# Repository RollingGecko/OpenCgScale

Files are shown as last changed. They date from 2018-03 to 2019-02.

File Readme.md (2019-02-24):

# Open CG-Scale

The complete project is open source. 

The weight and the CG is measured by 3 scale modules places under the landing gear of the airplane. Everything is powered by an ESP32.
The position of the CG is projected by a laser on the button of the plane. 

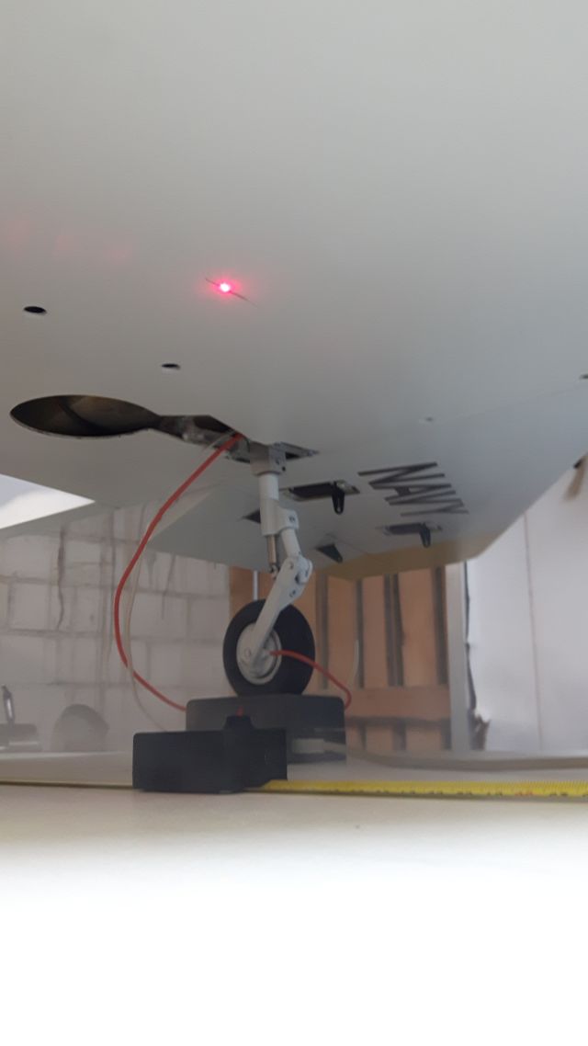
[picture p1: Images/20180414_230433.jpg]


Measuring of distance is supported by a laser, that points to the middle of the main gear.

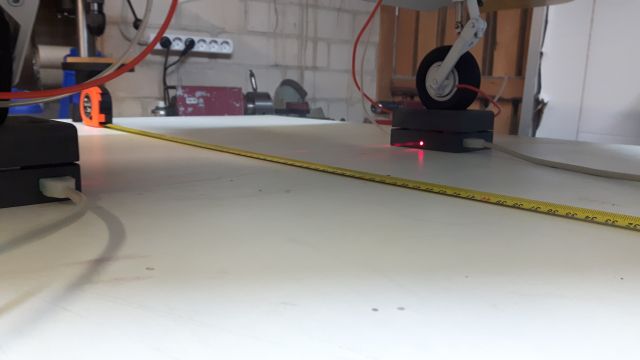
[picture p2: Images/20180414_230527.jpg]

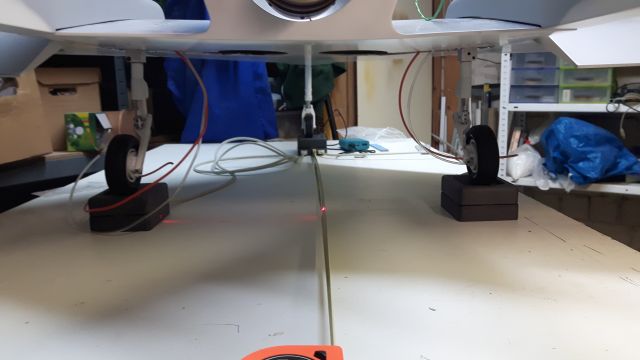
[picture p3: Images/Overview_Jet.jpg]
Overview Jet

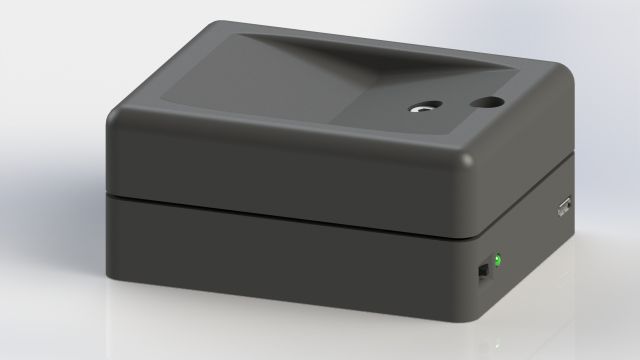
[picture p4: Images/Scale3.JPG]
Scale3


All information are shown on a Android app via bluetooth 4.0 low energy. The app was designed in [Thunkable](https://thunkable.com/#/). The design file is stored together
with the aplication AKP in the repo. [(Link)](https://github.com/RollingGecko/CgScale/tree/master/SRC/APP)

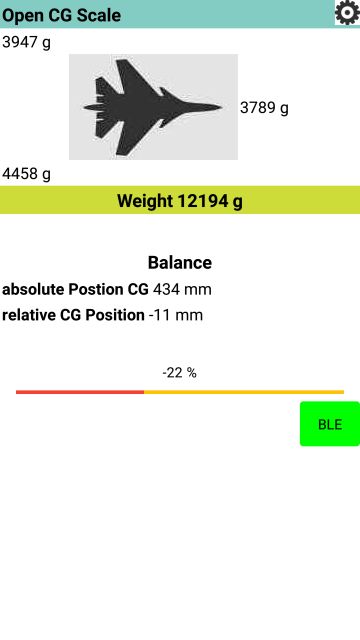
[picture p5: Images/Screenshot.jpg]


All parts are printed 3d. Files are provided as [(STL)](https://github.com/RollingGecko/CgScale/tree/master/Parts/STL). Some aluminium parts are required. But they can simply be cutted from aluminium profile [(PDF)](https://github.com/RollingGecko/CgScale/blob/master/Parts/Alu-Parts_Drawing.PDF).

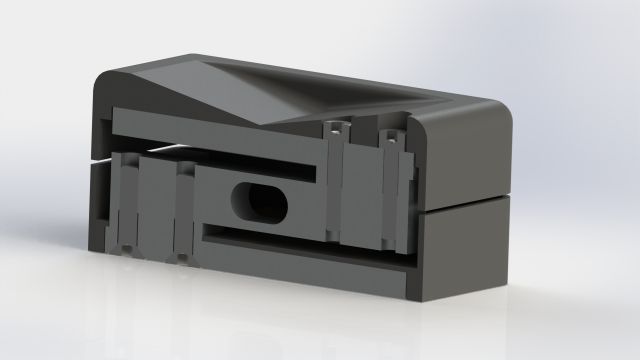
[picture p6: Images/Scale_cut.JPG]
Scale Cut


## Hardware
### Based on ESP32. 

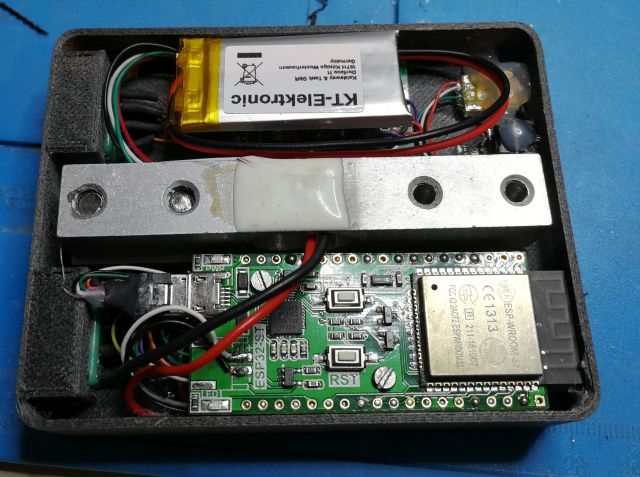
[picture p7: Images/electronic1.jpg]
Electronic1


* Used Board ESP32 WeMos LOLIN32 Lite V1.0.0
	* https://wiki.wemos.cc/products:lolin32:lolin32_lite
	* https://arduino-projekte.info/wemos-lolin32-lite/ (German)
* The Board provides an Lipo Battery Charger
### Scale

* Used 10 kg load cell together with the [HX-711](https://github.com/bogde/HX711.git) board you can find for example
  * on ebay: https://tinyurl.com/ybxn4rfh
  * on aliexpress: https://tinyurl.com/y78dd9gv

### Laser pointer module
 * From ebay like https://tinyurl.com/y8mcnznn
 * Aliexpress https://tinyurl.com/ydeltejj

## Used Libaries
* Used Libraries from espressif. See https://github.com/espressif/arduino-esp32/blob/master/docs/arduino-ide/boards_manager.md for installation.
* HX-711 Board: https://github.com/bogde/HX711.git

# Circuit

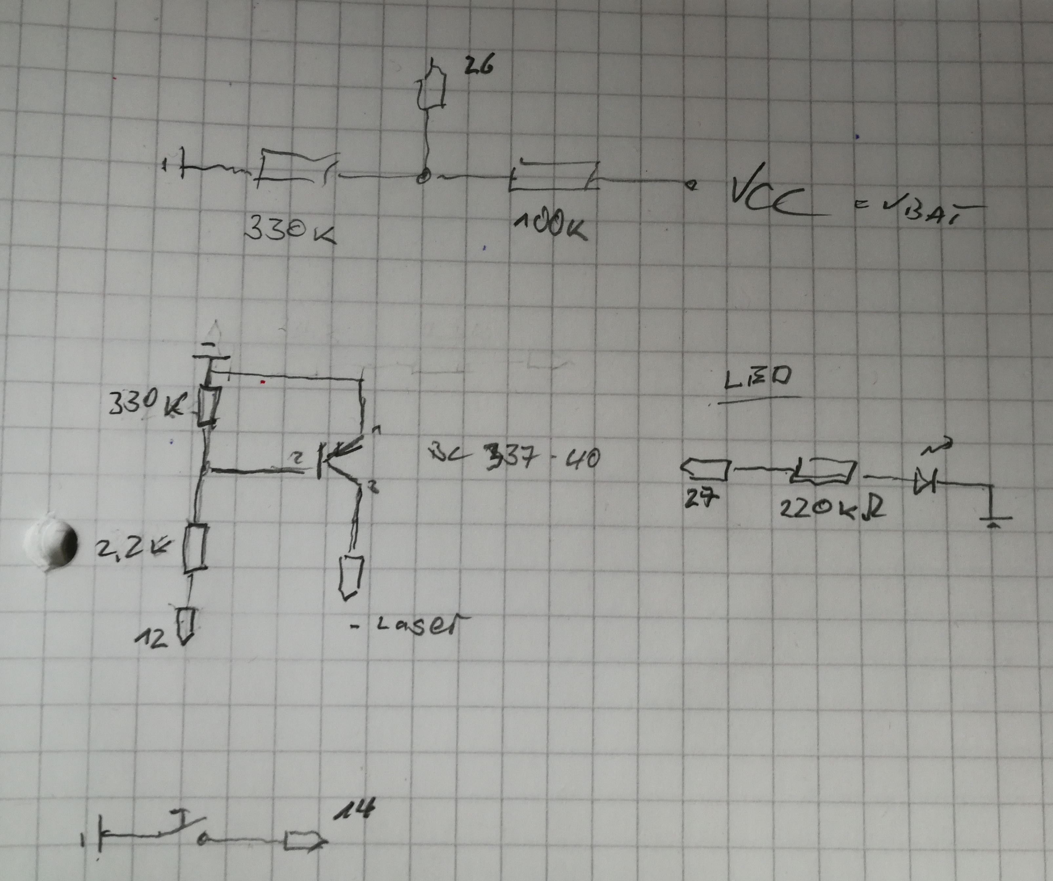
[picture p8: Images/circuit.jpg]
Circuit


The PIN-setting to the esp32 is configured in the config.h file.

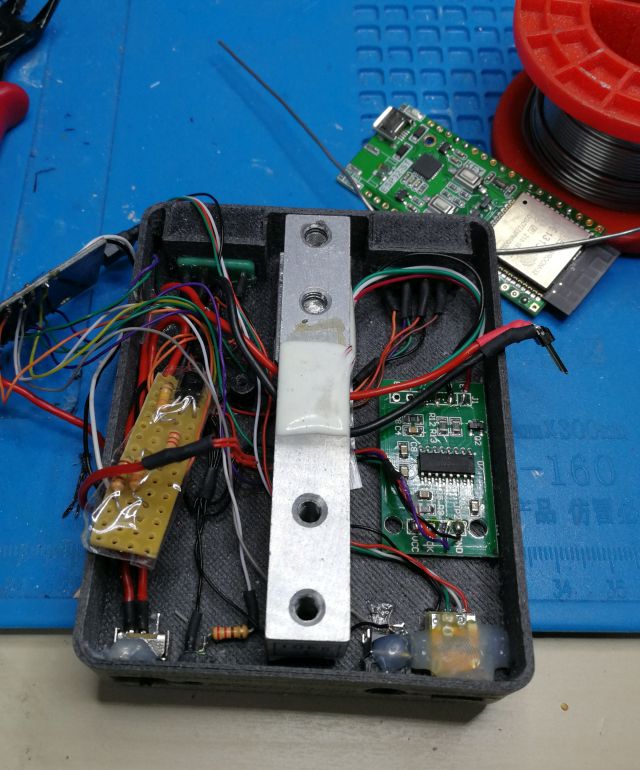
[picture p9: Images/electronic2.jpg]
Electronic2


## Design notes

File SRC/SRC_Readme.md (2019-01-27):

## Two programs available

### CG_Scale
The main finished program.

### ScaleBleDummy
A program to run a dummy on the ESP32 for APP - programming.

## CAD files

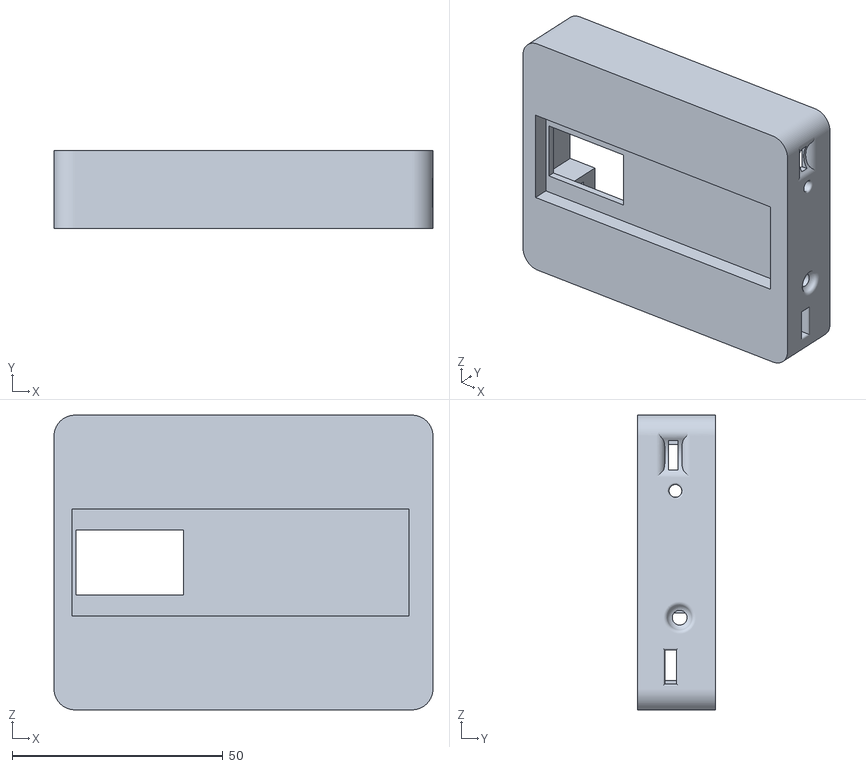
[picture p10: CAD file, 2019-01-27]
Parts/STL/CG_Scale_Main_Lower.STL
90.0 x 18.5 x 70.0

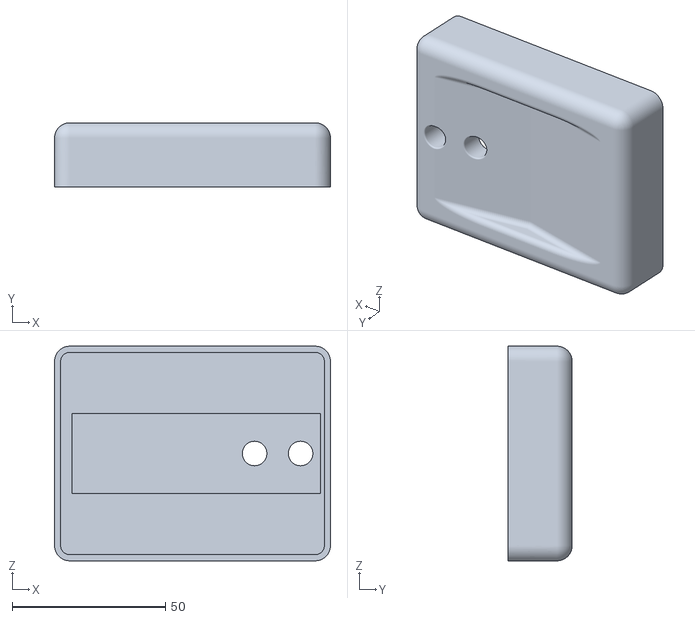
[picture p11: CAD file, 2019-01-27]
Parts/STL/CG_Scale_Main_Upper.STL
90.0 x 21.0 x 70.0

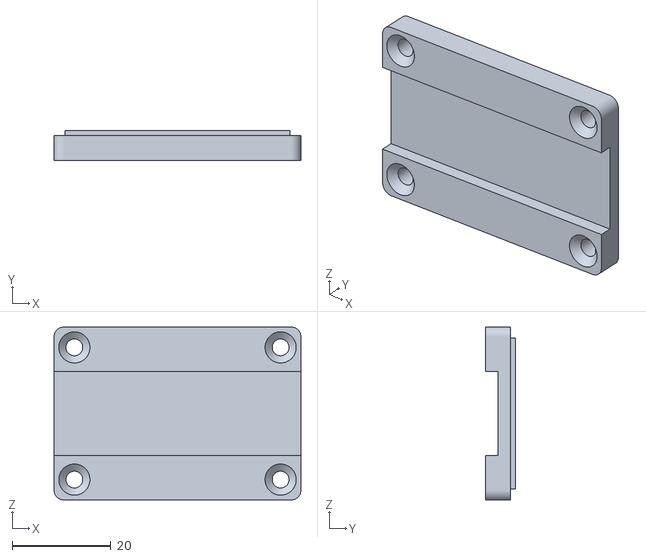
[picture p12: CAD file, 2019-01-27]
Parts/STL/CG_Laser_Pointer_Lower.STL
50.0 x 6.00 x 35.0

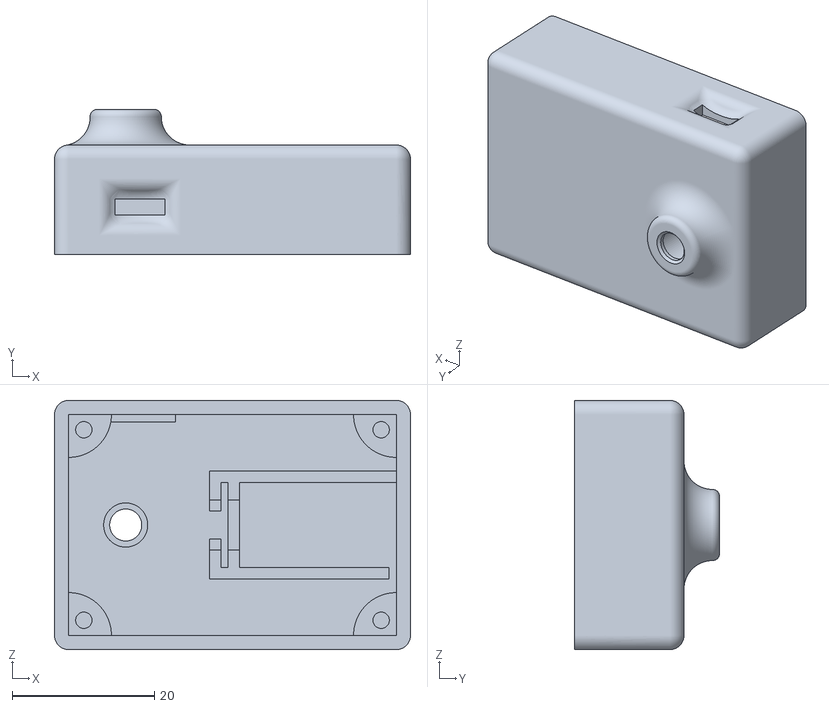
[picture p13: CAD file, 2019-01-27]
Parts/STL/CG_Laser_Pointer_Upper.STL
50.0 x 20.4 x 35.0

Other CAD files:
Parts/STL/CG_Scale_Lower_satelite.STL
Parts/STL/CG_Scale_Lower_Laser.STL

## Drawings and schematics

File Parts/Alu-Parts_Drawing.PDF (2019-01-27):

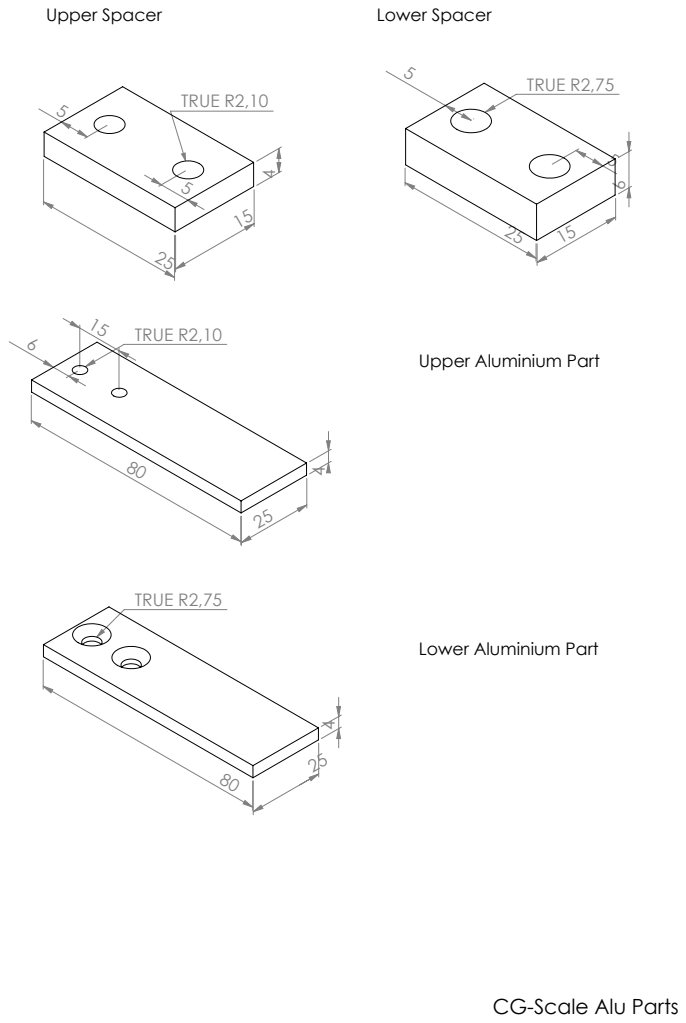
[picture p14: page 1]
TRUE R2,10 5; TRUE R2,10 15; TRUE R2,75; TRUE R2,75 5; Upper Spacer; Lower Spacer

Upper Aluminium Part

Lower Aluminium Part

CG-Scale Alu Parts

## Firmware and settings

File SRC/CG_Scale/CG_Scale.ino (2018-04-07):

#include "BLEDevice.h"
#include "BLEUtils.h"
#include "BLEServer.h"
#include "BLE2902.h"
#include "HX711.h"
#include "config.h"
#include "soc/rtc.h"

//Declaration of BLE Objects

bool deviceConnected = false;

BLECharacteristic *scaleValueMainCharacteristic;
BLECharacteristic *scaleValue1Characteristic;
BLECharacteristic *scaleValue2Characteristic;

//Declaratition of HX711 Scale Modules

HX711	scaleMain(SCALEDATAPIN_MAIN, SCALECLKPIN_MAIN, SCALEGAIN_MAIN);
HX711	scale1(SCALEDATAPIN_1, SCALECLKPIN_1, SCALEGAIN_1);
HX711	scale2(SCALEDATAPIN_2, SCALECLKPIN_2, SCALEGAIN_2);

int	ScaleReading_Main = 0.00;

//BLECharacteristic *configMeasureScale1Characteristic;
//BLECharacteristic *configMeasureScale2Characteristic;
//BLECharacteristic *configMeasureScale3Characteristic;

class MyServerCallbacks : public BLEServerCallbacks {
	void onConnect(BLEServer* pServer) {
		deviceConnected = true;
		Serial.println("Device connected.");
	};

	void onDisconnect(BLEServer* pServer) {
		deviceConnected = false;
		Serial.println("Device disconnected.");
	};
};


void setIntToCharacteristic(BLECharacteristic* charact, int value) {
	char txstr[8];
	itoa(value, txstr, 10);
	charact->setValue(txstr);
}

void scaleToBle(HX711* scale, BLECharacteristic* ble) {
	int scaleReading = 0;
	scale->read();
	scaleReading = round(scale->get_units(5));
	if (scaleReading <= 4)
	{
		scaleReading = 0;
	}

	Serial.print("Reading from ScaleModule: ");
	Serial.println(scaleReading);

	setIntToCharacteristic(ble, scaleReading);
	ble->notify();
}


volatile int buttonInterruptCount = 0;
unsigned long lastDebounceTime = 0;
unsigned long startButtonCountInterval = 0;
int numberOfInterrupts = 0;
portMUX_TYPE mux = portMUX_INITIALIZER_UNLOCKED;

boolean laserOn = false;

void IRAM_ATTR handleInterrupt() {
	portENTER_CRITICAL_ISR(&mux);
	buttonInterruptCount++;
	portEXIT_CRITICAL_ISR(&mux);
}

void setup() {
	pinMode(LED_PIN, OUTPUT);
	digitalWrite(LED_PIN, HIGH);

	pinMode(LASER_PIN, OUTPUT);

	pinMode(BUTTON_PIN, INPUT_PULLUP);
	attachInterrupt(digitalPinToInterrupt(BUTTON_PIN), handleInterrupt, FALLING);

	Serial.begin(115200);
		
	//Initializing the scale
	Serial.println("Intizialing Scale....in 5 seconds");
	delay(5000);
	scaleMain.set_scale(SCALEFACTOR_MAIN);
	scaleMain.tare();
	Serial.println("Initializiation Main done.");
	scale1.set_scale(SCALEFACTOR_1);
	scale1.tare();
	Serial.println("Initializiation one done.");
	scale2.set_scale(SCALEFACTOR_2);
	scale2.tare();
	Serial.println("Initializiation two done.");

	Serial.println("Starting BLE work!");
	//Create a server
	BLEDevice::init("CG Scale");
	BLEServer *pServer = BLEDevice::createServer();
	pServer->setCallbacks(new MyServerCallbacks());
	//Create Service for CG Measuring
	BLEService *scaleService = pServer->createService(SCALE_SERVICE_UUID);
	//Define characteristics for measuring Service

	scaleValueMainCharacteristic = scaleService->createCharacteristic(
		SCALE_VALUE_MAIN_CHARACTERISTIC_UUID,
		BLECharacteristic::PROPERTY_READ |
		BLECharacteristic::PROPERTY_NOTIFY
	);
	scaleValue1Characteristic = scaleService->createCharacteristic(
		SCALE_VALUE_1_CHARACTERISTIC_UUID,
		BLECharacteristic::PROPERTY_READ |
		BLECharacteristic::PROPERTY_NOTIFY
	);
	scaleValue2Characteristic = scaleService->createCharacteristic(
		SCALE_VALUE_2_CHARACTERISTIC_UUID,
		BLECharacteristic::PROPERTY_READ |
		BLECharacteristic::PROPERTY_NOTIFY
	);

	scaleValueMainCharacteristic->addDescriptor(new BLE2902());
	scaleValue1Characteristic->addDescriptor(new BLE2902());
	scaleValue2Characteristic->addDescriptor(new BLE2902());

	//Create Service for CG Configuration

	//BLEService *configService = pServer->createService(CONFIG_SERVICE_UUID);

	//Define Characteristics for Config Service
	//configMeasureScale1Characteristic = configService->createCharacteristic(
	//	CONFIG_MEASURESCALE1_CHARACTERISTIC_UUID,
	//	BLECharacteristic::PROPERTY_READ |
	//	BLECharacteristic::PROPERTY_WRITE
	//);
	//configMeasureScale2Characteristic = configService->createCharacteristic(
	//	CONFIG_MEASURESCALE2_CHARACTERISTIC_UUID,
	//	BLECharacteristic::PROPERTY_READ |
	//	BLECharacteristic::PROPERTY_WRITE
	//);
	//configMeasureScale3Characteristic = configService->createCharacteristic(
	//	CONFIG_MEASURESCALE3_CHARACTERISTIC_UUID,
	//	BLECharacteristic::PROPERTY_READ |
	//	BLECharacteristic::PROPERTY_WRITE
	//);



	scaleValue1Characteristic->setValue("1200.01");

	//Start Services
	scaleService->start();
	//configService->start();

	BLEAdvertising *pAdvertising = pServer->getAdvertising();
	pAdvertising->start();
	Serial.println("Waiting a client connection to notify...");

}


void loop() {

	//Blocking the look during button counting intervall
	while (buttonInterruptCount>0 || numberOfInterrupts > 0)
	{
		if (buttonInterruptCount>0) {

			portENTER_CRITICAL(&mux);
			buttonInterruptCount--;
			portEXIT_CRITICAL(&mux);
			//Debouncing button
			if ((millis() - lastDebounceTime >= DEBOUNCEDELAY))
			{
				lastDebounceTime = millis();
				numberOfInterrupts++;
				Serial.print("An interrupt has occurred. Total: ");
				Serial.println(numberOfInterrupts);
				//Set start of counting Interval
				if (numberOfInterrupts == 1)
				{
					startButtonCountInterval = millis();
				}
			}
		}

		if (millis() - startButtonCountInterval > COUNTINTERVAL && numberOfInterrupts > 0)
		{
			Serial.print("Number of counts in Interval: ");
			Serial.println(numberOfInterrupts);
			
			switch (numberOfInterrupts)
			{
			case 1:
				Serial.println("Laser on");
				if (!laserOn)
				{
					digitalWrite(LASER_PIN, HIGH);
					laserOn = true;
					Serial.println("Laser on");
				}

				else
				{
					digitalWrite(LASER_PIN, LOW);
					laserOn = false;
					Serial.println("Laser off");
				}
				

				break;
			case 2:
				break;
			case 3:
				break;
			default:
				break;
			}
			numberOfInterrupts = 0;
		}
	}

	
	
	if (deviceConnected)
	{
		//Reading the scale modules

		scaleToBle(&scaleMain, scaleValueMainCharacteristic); 
		scaleToBle(&scale1, scaleValue1Characteristic);
		scaleToBle(&scale2, scaleValue2Characteristic);
		
		
		
		delay(500);
	}

}

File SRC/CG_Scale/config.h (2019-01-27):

#ifndef _CONFIG_h
#define _CONFIG_h

//Pinsettings

#define SERIAL_SPEED			115200

//Himalaya ESP32

//#define SCALEDATAPIN_MAIN		25
//#define SCALECLKPIN_MAIN		26
//#define SCALEDATAPIN_1			32
//#define SCALECLKPIN_1			33
//#define SCALEDATAPIN_2			18
//#define SCALECLKPIN_2			19
//
//#define LASER_PIN				27
//#define BUTTON_PIN				21
//#define LED_PIN					14
//#define VOLTAGE_ACCU_PIN		12

//WEMOS Lolin32

#define SCALEDATAPIN_MAIN		13
#define SCALECLKPIN_MAIN		15
#define SCALEDATAPIN_1			2
#define SCALECLKPIN_1			0
#define SCALEDATAPIN_2			04
#define SCALECLKPIN_2			16

#define LASER_PIN				12
#define BUTTON_PIN				14
#define LED_PIN					27
#define VOLTAGE_ACCU_PIN		26

#define SCALEGAIN_MAIN			128
#define SCALEGAIN_1				128
#define SCALEGAIN_2				128

#define SCALEFACTOR_MAIN		207.00
#define SCALEFACTOR_1			210.61
#define SCALEFACTOR_2			199.73

#define SCALENUMBEROFAVERAGECYCLES	5

//BLE Settings
//Definition of service and characteristic UUIDs
//Scale Service
#define SCALE_SERVICE_UUID						"4fafc201-1fb5-459e-8fcc-c5c9c331914b"
#define SCALE_VALUE_MAIN_CHARACTERISTIC_UUID	"beb5483e-36e1-4688-b7f5-ea07361b26a8"
#define SCALE_VALUE_1_CHARACTERISTIC_UUID		"08bd3bdc-208b-11e8-b467-0ed5f89f718b"
#define SCALE_VALUE_2_CHARACTERISTIC_UUID		"1381e72a-208b-11e8-b467-0ed5f89f718b"
//Config Service
//#define CONFIG_SERVICE_UUID							"1cb82d5e-208b-11e8-b467-0ed5f89f718b"
//#define	CONFIG_MEASURESCALE1_CHARACTERISTIC_UUID	"255066de-208b-11e8-b467-0ed5f89f718b"
//#define	CONFIG_MEASURESCALE2_CHARACTERISTIC_UUID	"2cce3d28-208b-11e8-b467-0ed5f89f718b"
//#define	CONFIG_MEASURESCALE3_CHARACTERISTIC_UUID	"3625ec68-208b-11e8-b467-0ed5f89f718b"
//Laser Service
#define LASER_SERVICE_UUID					"960c2dd9-875f-44b1-8104-d67a5fbf3ce0"
#define LASER_SWITCH_CHARACTERISTIC_UUID	"a0460204-3062-11e8-b467-0ed5f89f718b"
#endif

//Button Count Settings

#define DEBOUNCEDELAY 200
#define COUNTINTERVAL 1500

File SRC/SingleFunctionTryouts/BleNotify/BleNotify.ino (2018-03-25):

/*
Video: https://www.youtube.com/watch?v=oCMOYS71NIU
Based on Neil Kolban example for IDF: https://github.com/nkolban/esp32-snippets/blob/master/cpp_utils/tests/BLE%20Tests/SampleNotify.cpp
Ported to Arduino ESP32 by Evandro Copercini

Create a BLE server that, once we receive a connection, will send periodic notifications.
The service advertises itself as: 4fafc201-1fb5-459e-8fcc-c5c9c331914b
And has a characteristic of: beb5483e-36e1-4688-b7f5-ea07361b26a8

The design of creating the BLE server is:
1. Create a BLE Server
2. Create a BLE Service
3. Create a BLE Characteristic on the Service
4. Create a BLE Descriptor on the characteristic
5. Start the service.
6. Start advertising.

A connect hander associated with the server starts a background task that performs notification
every couple of seconds.
*/
#include <BLEDevice.h>
#include <BLEServer.h>
#include <BLECharacteristic.h>
#include <BLEUUID.h>
#include <BLEUtils.h>
#include <BLE2902.h>
#include <stdlib.h>

BLECharacteristic *pCharacteristic;
bool deviceConnected = false;
uint8_t value = 0;

// See the following for generating UUIDs:
// https://www.uuidgenerator.net/

#define SERVICE_UUID        "4fafc201-1fb5-459e-8fcc-c5c9c331914b"
#define CHARACTERISTIC_UUID "beb5483e-36e1-4688-b7f5-ea07361b26a8"


class MyServerCallbacks : public BLEServerCallbacks {
	void onConnect(BLEServer* pServer) {
		deviceConnected = true;
	};

	void onDisconnect(BLEServer* pServer) {
		deviceConnected = false;
	 
};


void setIntToCharacteristic(BLECharacteristic* charact, int value) {
	char txstr[8];
	itoa(value, txstr, 10);
	charact->setValue(txstr);
}


//class IntCharacteristic : public BLECharacteristic {
//	IntCharacteristic(const char* myuuid, uint32_t properties = 0) : BLECharacteristic(myuuid,properties) {
//		setIntValue(0);
//	}
//	void setIntValue(int temp) {
//		char strValue[8];
//		itoa(temp, strValue, 10);
//		setValue(strValue);
//	}
//	int getIntValue() {
//		std::string value = getValue();
//		char charValue[6];
//		strcpy(charValue, value.c_str());
//		return atoi(charValue);
//	}
//};

//IntCharacteristic *pCharacteristic;

void setup() {
	Serial.begin(115200);

	// Create the BLE Device
	BLEDevice::init("MyESP32");

	// Create the BLE Server
	BLEServer *pServer = BLEDevice::createServer();
	pServer->setCallbacks(new MyServerCallbacks());

	// Create the BLE Service
	BLEService *pService = pServer->createService(SERVICE_UUID);

	// Create a BLE Characteristic
	pCharacteristic = pService->createCharacteristic(
		CHARACTERISTIC_UUID,
		BLECharacteristic::PROPERTY_READ |
		BLECharacteristic::PROPERTY_WRITE |
		BLECharacteristic::PROPERTY_NOTIFY |
		BLECharacteristic::PROPERTY_INDICATE
	);

	// https://www.bluetooth.com/specifications/gatt/viewer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
	// Create a BLE Descriptor
	pCharacteristic->addDescriptor(new BLE2902());

	// Start the service
	pService->start();

	// Start advertising
	pServer->getAdvertising()->start();
	Serial.println("Waiting a client connection to notify...");
}

void loop() {

	if (deviceConnected) {
		Serial.printf("*** NOTIFY: %d ***\n", value);
		setIntToCharacteristic(pCharacteristic, value);
		//pCharacteristic->setValue(&value, 1);
		pCharacteristic->notify();
		//pCharacteristic->indicate();
		value++;
	}
	delay(2000);
}

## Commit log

2018-03-11 Initial with problem in class usage
    [BleNotify.ino]
2018-03-25 Working Scale Test for one sensor. Moved from CG_Scale
2018-04-01 Individual Scalefactor for prototype set
2018-04-07 Button click counter and laser switch added
2019-01-27 Circuit added
2019-01-27 STL files and alu part drawing added
    [CG_Laser_Pointer_Lower.STL, CG_Laser_Pointer_Upper.STL, CG_Scale_Lower_Laser.STL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]
2019-01-27 Links ato STL added
